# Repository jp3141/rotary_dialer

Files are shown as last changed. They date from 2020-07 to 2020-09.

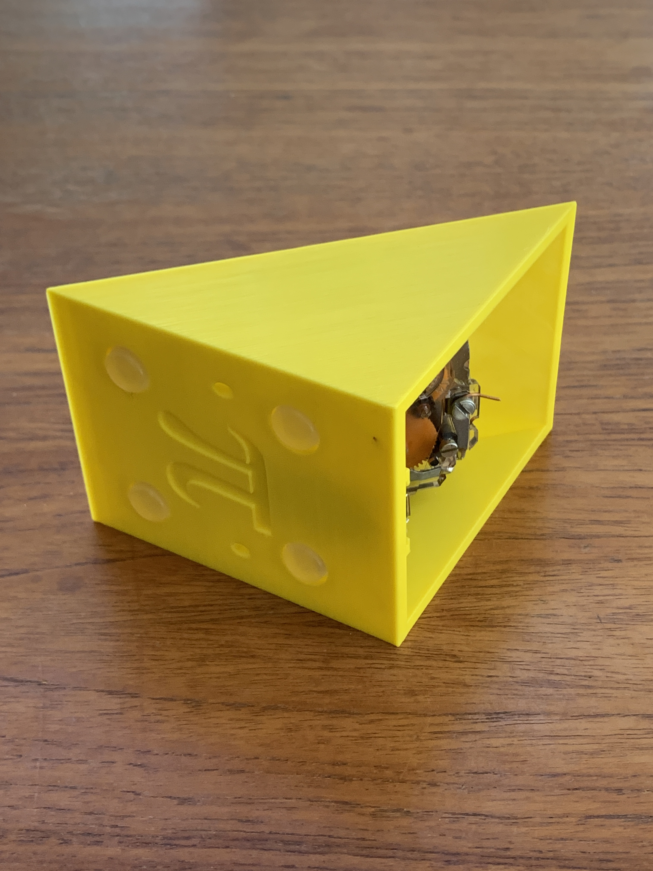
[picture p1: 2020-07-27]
Rotary numpad Side.JPG

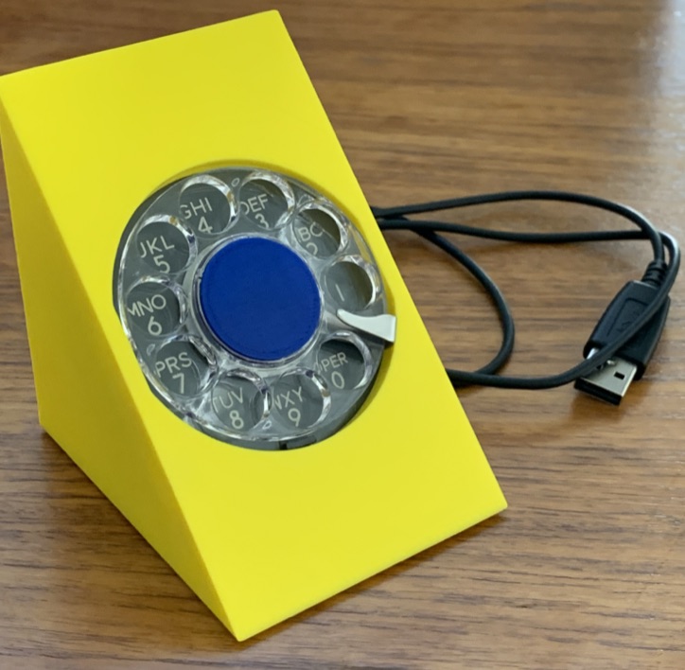
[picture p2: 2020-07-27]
Dialer Front.jpg

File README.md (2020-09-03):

# rotary_dialer
Use old telephone rotary dial as a USB numeric keypad; includes 3-D printer files. [Video at YouTube](https://www.youtube.com/watch?v=j2RmRgkIrfg)

Use an old AT&T Trimline rotary dialer as a numeric keypad for your computer. Disassemble the phone handset and extract the dialer. The 3-D files include a replacement for the center plug -- so you can change the colour.

Uses a Teensy 3.x or Teensy LC to read the pulses. One pin of the teensy is set as a weak pullup (INPUT_PULLUP) and the program counts the number of (debounced) positive pulses, representing the number dialled. It then sends that as a keystroke to the computer as a USB HID keyboard. The on-board LED flashes in synch with the dialer pulses.

The program also acts as a USB serial port -- for debugging. When initialized, the LED flashes quickly for up to 10 s while the serial port initializes, or the first number is dialed. You do not need to use the serial port for the keypad to work. 

The 3-D printed enclosure prints as a single piece; the center plug is also included. There is a slot for the Teensy, and mounting holes for a Trimline dialer. Use three #4 x 1/4" sheet metal screws to attach the dialer to the enclosure. If you cannot get 1/4" screws, use longer ones and cut to size. There are holes in the baseplate to allow a screwdriver to reach the bottom screws. 

The baseplate also includes an inverted truncated cone (frustrum) to hold small 12 mm rubber feet securely.

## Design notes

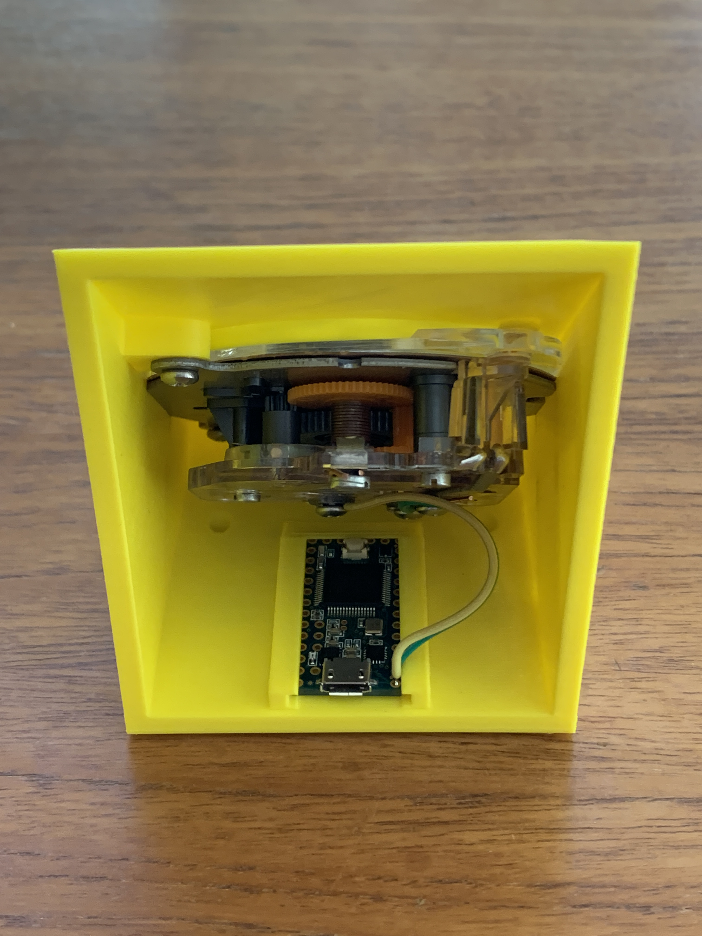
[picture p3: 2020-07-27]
Rotary Numpad Back.JPG

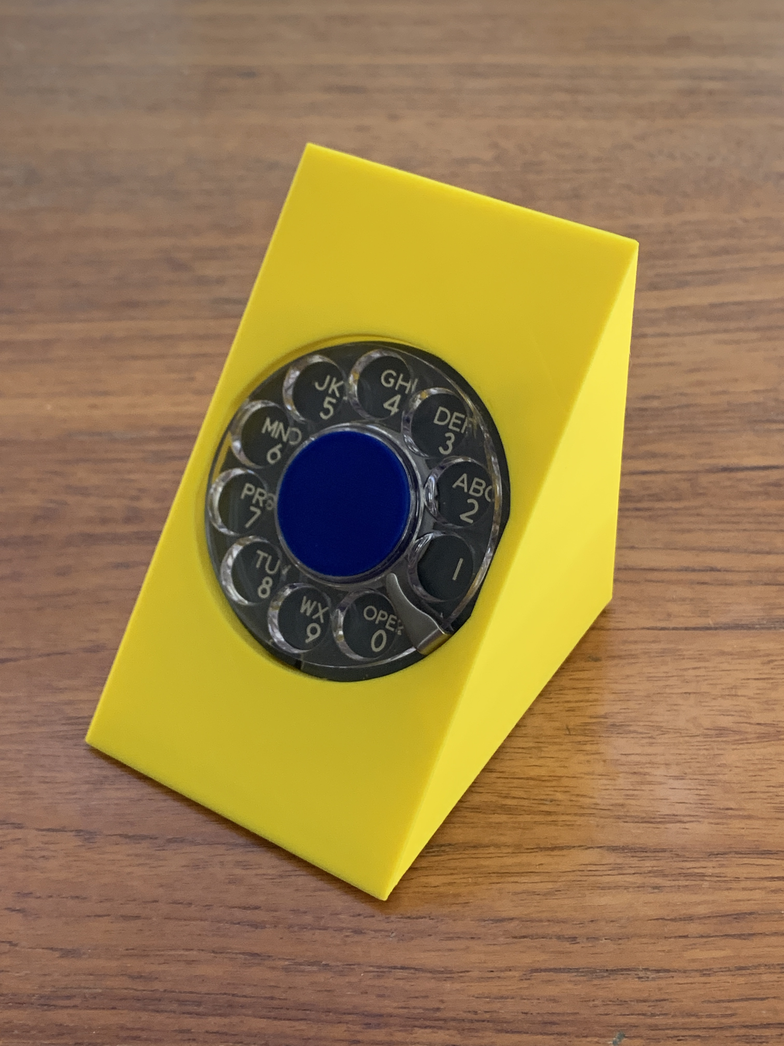
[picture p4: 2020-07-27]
Rotary Numpad Right.JPG

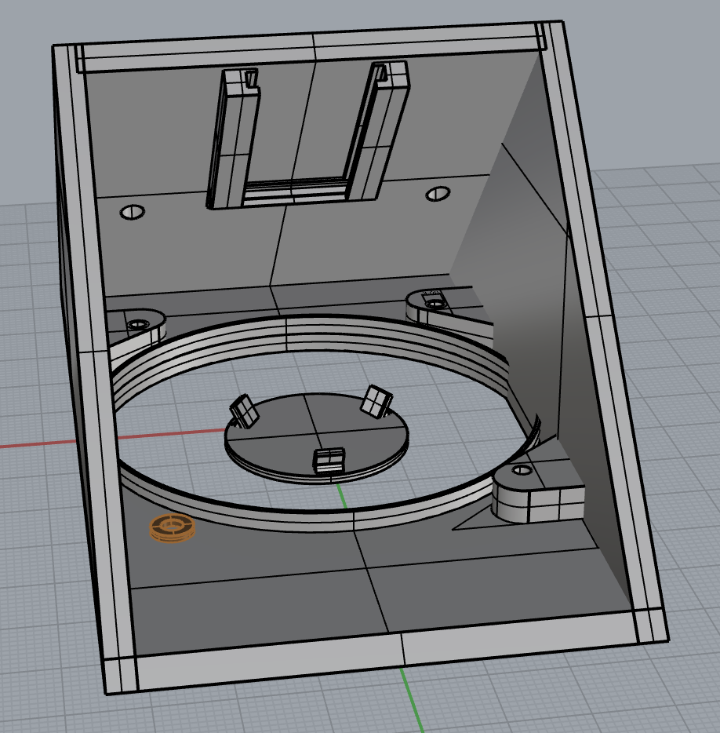
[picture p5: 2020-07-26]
Rotary Holder.png

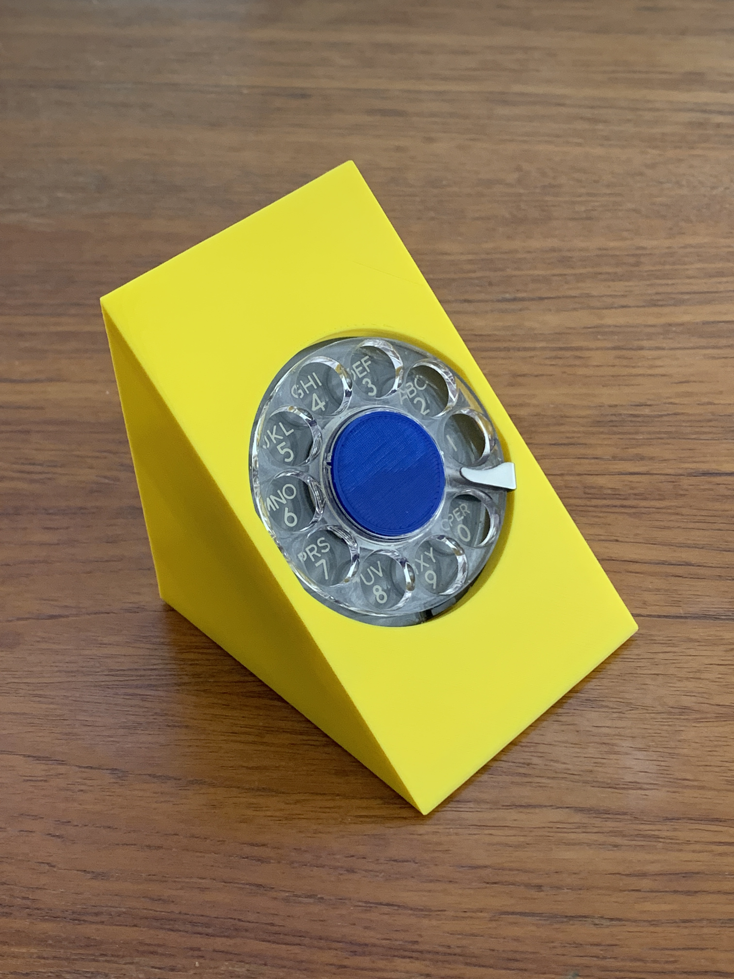
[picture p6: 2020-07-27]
rotary Numpad Left.JPG

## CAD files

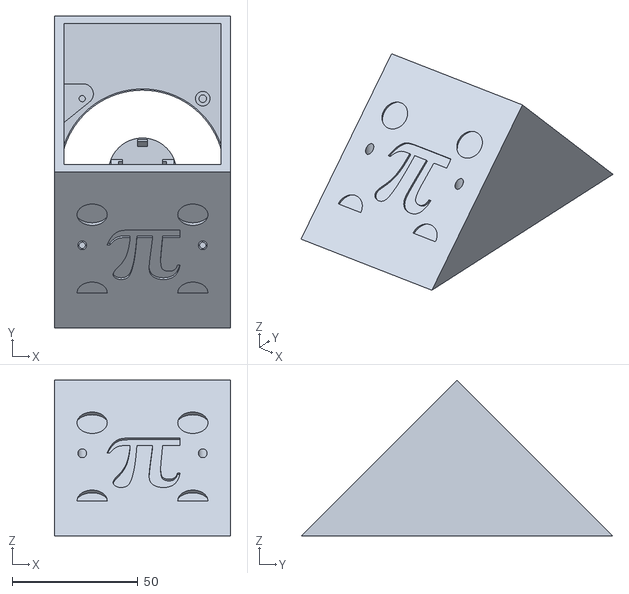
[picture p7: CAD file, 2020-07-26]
Ringer Box.stl
70.0 x 124.0 x 62.0

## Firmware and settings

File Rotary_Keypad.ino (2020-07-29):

 
// For Teensy 3.x, or Teensy LC
// Choose 'USB Type' to be "Keyboard", or "Serial + Keyboard + ..."
// edit boards.txt and usb_desc.h to add Serial + Keyboard option

// Uses name.c to change USB name

#include "Keyboard.h"

//            ___      ___    ___
//____________| |______| |____| |______//_____
//     (L,     H)  (L,  H  (L, H)        N

const int LED = 13;
const int DialPin = 0; // connect dialer to upper top left pins (GND & pin 0)
unsigned long now, lastDialedTime;
unsigned int NPulses = 0;

void setup() {
  pinMode(LED, OUTPUT); digitalWrite(LED, LOW);
  pinMode(DialPin, INPUT_PULLUP); delay(1);
  Keyboard.begin();
  Serial.begin(9600);
  now = millis();
  while(!(Serial || ((millis()-now) > 10000) || digitalRead(DialPin))) { // flash LED for 10 s or until dial activates or serial port is opened
    digitalWrite(LED, HIGH); delay(3);
    digitalWrite(LED, LOW);  delay(100-3);
  }

  Serial.println("Compiled " __FILE__ " " __DATE__ " "  __TIME__);
  #include "printme.h"
  lastDialedTime = millis();
  Serial.print("> ");
}

void loop() {
  now = millis();
  while (!digitalRead(DialPin)) { // while pin is low 
    if ( ((millis()-now) > 100) && (NPulses > 0)) { // send keystroke if timeout and at least one pulse
      if ((millis()-lastDialedTime) > 5000) Serial.print(F("\n> "));
      lastDialedTime = millis();
      if (NPulses <= 10) { 
        Keyboard.print(NPulses % 10);
        Serial.print(NPulses % 10);      
      } // send it
      NPulses = 0;
    }
  } // loop until pulse starts ==> pin is not low
//  Serial.printf("%c3(%2i,", NPulses==0 ? '\n': ' ', millis()-now); now = millis();
  Serial.printf("%c(%2i,", NPulses ? ' ': '\n', millis()-now); now = millis();
  digitalWrite(LED, HIGH);   // pulse starts
  delay(5);  //debounce
  while (digitalRead(DialPin)); // loop while pulse is high
  Serial.printf("%2i) ",millis()-now);
  NPulses++; // count pulse  
  digitalWrite(LED, LOW);
  delay(5); //debounce falling edge
  
} 

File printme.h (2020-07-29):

Serial.println("\
 \n\
// For Teensy 3.x, or Teensy LC\n\
// Choose 'USB Type' to be \"Keyboard\", or \"Serial + Keyboard + ...\"\n\
// edit boards.txt and usb_desc.h to add Serial + Keyboard option\n\
\n\
// Uses name.c to change USB name\n\
\n\
#include \"Keyboard.h\"\n\
\n\
//            ___      ___    ___\n\
//____________| |______| |____| |______//_____\n\
//     (L,     H)  (L,  H  (L, H)        N\n\
\n\
const int LED = 13;\n\
const int DialPin = 0; // connect dialer to upper top left pins (GND & pin 0)\n\
unsigned long now, lastDialedTime;\n\
unsigned int NPulses = 0;\n\
\n\
void setup() {\n\
  pinMode(LED, OUTPUT); digitalWrite(LED, LOW);\n\
  pinMode(DialPin, INPUT_PULLUP); delay(1);\n\
  Keyboard.begin();\n\
  Serial.begin(9600);\n\
  now = millis();\n\
  while(!(Serial || ((millis()-now) > 10000) || digitalRead(DialPin))) { // flash LED for 10 s or until dial activates or serial port is opened\n\
    digitalWrite(LED, HIGH); delay(3);\n\
    digitalWrite(LED, LOW);  delay(100-3);\n\
  }\n\
\n\
  Serial.println(\"Compiled \" __FILE__ \" \" __DATE__ \" \"  __TIME__);\n\
  #include \"printme.h\"\n\
  lastDialedTime = millis();\n\
  Serial.print(\"> \");\n\
}\n\
\n\
void loop() {\n\
  now = millis();\n\
  while (!digitalRead(DialPin)) { // while pin is low \n\
    if ( ((millis()-now) > 100) && (NPulses > 0)) { // send keystroke if timeout and at least one pulse\n\
      if ((millis()-lastDialedTime) > 5000) Serial.print(F(\"\\n> \"));\n\
      lastDialedTime = millis();\n\
      if (NPulses <= 10) { \n\
        Keyboard.print(NPulses % 10);\n\
        Serial.print(NPulses % 10);      \n\
      } // send it\n\
      NPulses = 0;\n\
    }\n\
  } // loop until pulse starts ==> pin is not low\n\
//  Serial.printf(\"%c3(%2i,\", NPulses==0 ? '\\n': ' ', millis()-now); now = millis();\n\
  Serial.printf(\"%c(%2i,\", NPulses ? ' ': '\\n', millis()-now); now = millis();\n\
  digitalWrite(LED, HIGH);   // pulse starts\n\
  delay(5);  //debounce\n\
  while (digitalRead(DialPin)); // loop while pulse is high\n\
  Serial.printf(\"%2i) \",millis()-now);\n\
  NPulses++; // count pulse  \n\
  digitalWrite(LED, LOW);\n\
  delay(5); //debounce falling edge\n\
  \n\
} \n\
");

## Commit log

2020-07-26 Add files via upload
    Arduino code for Teensy
2020-07-29 Add files via upload
    Updated -- smaller code, prints pulse timing on serial port;
    Run 'printme.sh' to generate 'print.h' which is then #included in the .ino and prints itself to the serial port when started
